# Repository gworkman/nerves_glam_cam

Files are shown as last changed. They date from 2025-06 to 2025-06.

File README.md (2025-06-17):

# Nerves Glam Cam

A Nerves-powered conference badge, first displayed at ElixirConf EU 2025.
Featuring an e-ink display and a tiny onboard camera, this project is designed
to showcase a fun use-case of Nerves.

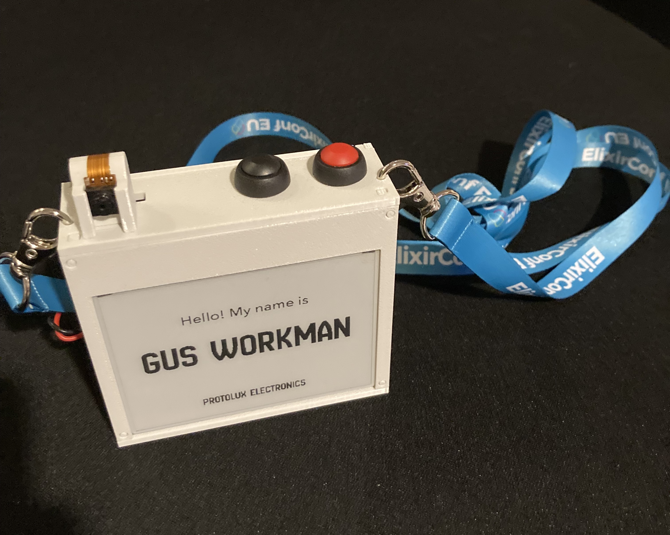
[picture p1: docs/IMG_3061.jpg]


> [!NOTE]
> Do you want to learn how to write an e-ink driver and get some e-ink hardware
> to take home? I'm running a workshop at several upcoming conferences, based on
> this project. Check it out -
> [ElixirConf US](https://elixirconf.com/trainings/dip-your-toes-into-hardware-with-nerves/)
> and
> [CodeBEAM Europe](https://codebeameurope.com/trainings/dip-your-toes-into-hardware-with-nerves/)
>
> Feel free to contact me if you're interested or have any questions!

## Functions

| Button | Press Type | Action |
| --- | --- | --- |
| Red | Any | Capture an image and show it on the display |
| Black  | Short | Cycle through the loaded slides |
| Black  | Long (5s)  | Power off (low power mode) |

## Hardware

Nerves Glam Cam is made of several components:

- Raspberry Pi Zero 2W
- [Soleil](https://protolux.io/projects/soleil) board for power management,
  battery charging and sleep mode
- 4.2", 400x300 e-ink display (I used
  [this one from Good Display](https://www.good-display.com/product/386.html))
- 24-pin e-ink SPI display adapter (I used
  [this one from Good Display](https://www.good-display.com/product/516.html))
- Tiny MIPI-CSI2 camera (I used
  [this OV5647-based one from AliExpress](https://www.aliexpress.com/item/32782501654.html))
- Some 3D printed parts and some superglue. STEP files are available in the
  [`mechanical`](/mechanical/README.md) directory

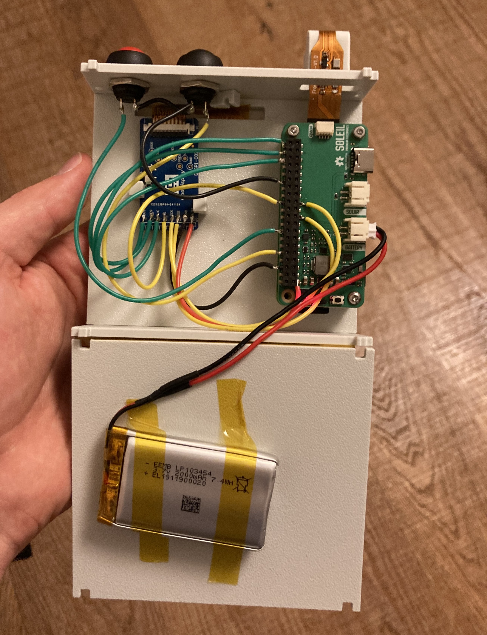
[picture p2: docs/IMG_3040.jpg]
Nerves Glam Cam - under the hood


## Key Implementation Details

It's a surprisingly small amount of code required to build this app and make it
run. There's two areas which are not super trivial though:

### E-Ink Display Driver

The e-ink display contains a SSD1683 driver chip, and is controlled using an SPI
interface. The `NervesGlamCam.EInk` module handles initialization, configuring
parameters like dimensions and operating mode, writing pixel data to the display
buffer, and enabling power-saving sleep mode.

The
[device datasheet](https://v4.cecdn.yun300.cn/100001_1909185148/GDEY042T81.pdf)
contains example code which served as the starting point for the software driver
in this repo.

### Image Processing

Images go through a standard processing pipeline to prepare them for display.
The source of the images can be static images (such as the pre-rendered slides,
which are just JPEG files) or dynamic images captured by the camera. First, an
image is converted to black and white, then resized to fit the screen
dimensions, and finally dithered using the Floyd-Steinberg algorithm. To handle
dithering, I cross compiled the Rust-based
[dither tool](https://crates.io/crates/dither) by Efron Licht. Finally, the
processed image is formatted to match the display driver requirements and
written to the buffer for rendering.

## Getting Started

If you've gone through the trouble of acquiring all the hardware, and want to
run this on your own device:

- `export MIX_TARGET=soleil_rpi0_2` or prefix every command with
  `MIX_TARGET=soleil_rpi0_2`. If you don't have the Soleil board for power
  management, you can also just use a target of `rpi0_2`.
- Set your WiFi credentials as environment variables, `NERVES_WIFI_SSID` and
  `NERVES_WIFI_PASSPHRASE`
- Install dependencies with `mix deps.get`
- Create firmware with `mix firmware`
- Burn to an SD card with `mix burn`

## Future Updates

The first version as shown at ElixirConf EU 2025 was bare-bones (I threw it
together in a weekend!). For the next conference, I'd like to make a few
updates:

- [ ] Support 4-bit grayscale for nicer images (especially text and fonts)
- [ ] Better button debounce
- [ ] More static slides
- [ ] Make it more social and interactive!

Stay tuned... v2 coming at Goatmire in September 2025 :eyes:

## Gallery

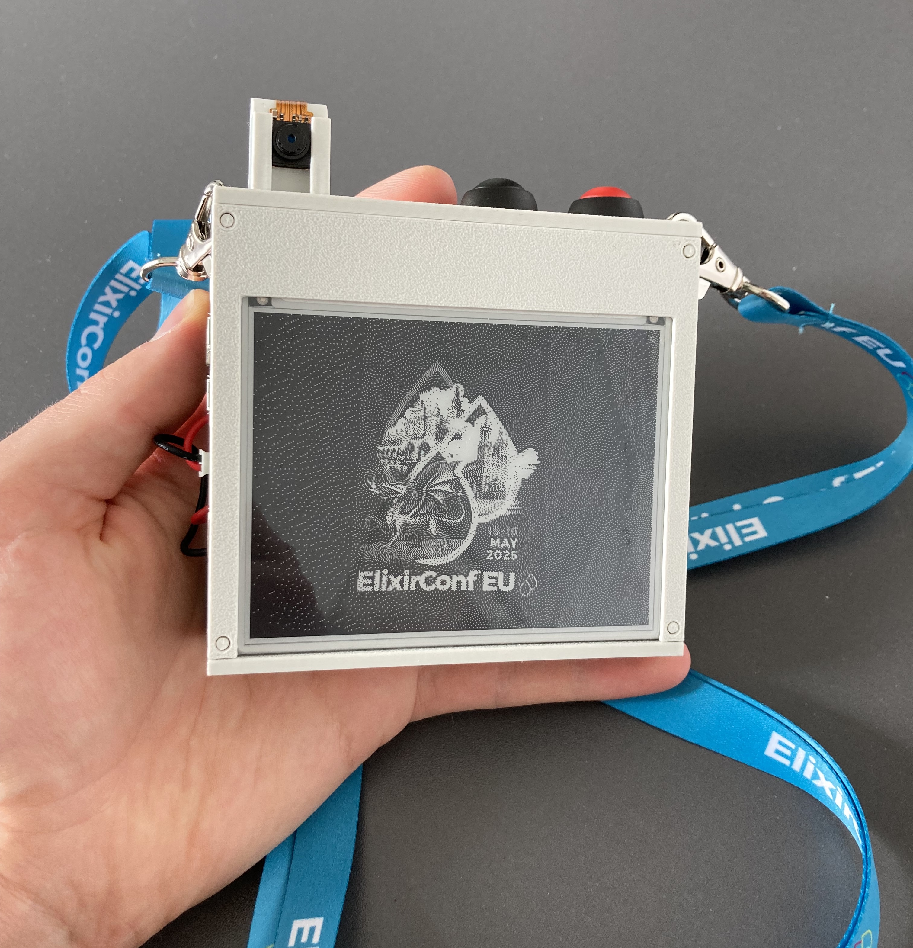
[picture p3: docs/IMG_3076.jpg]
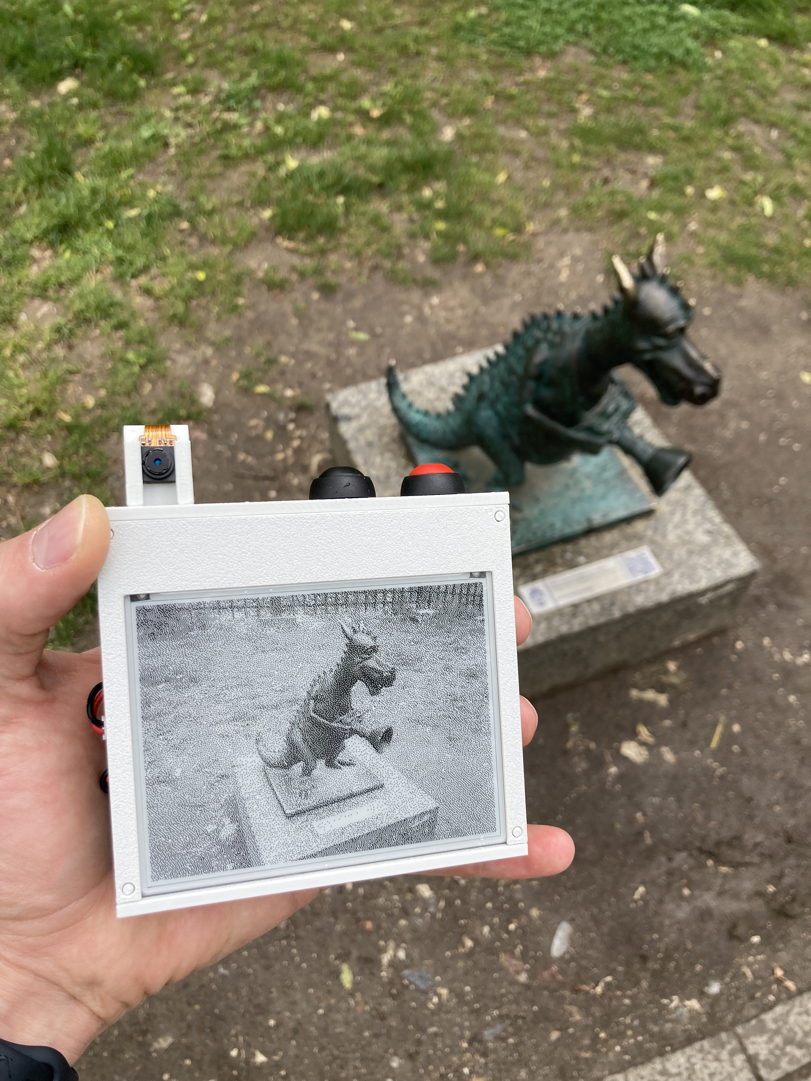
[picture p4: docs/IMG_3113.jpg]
 
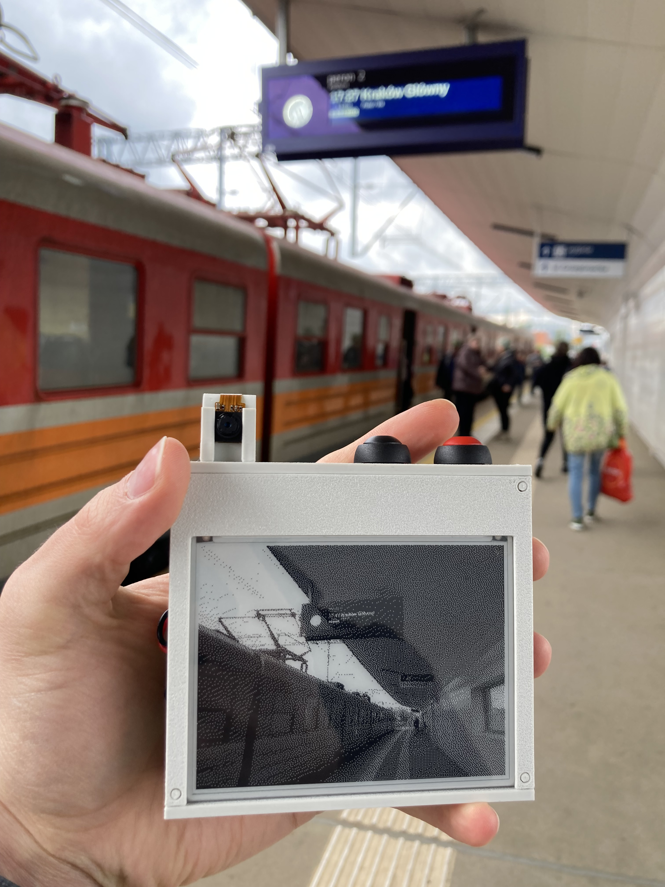
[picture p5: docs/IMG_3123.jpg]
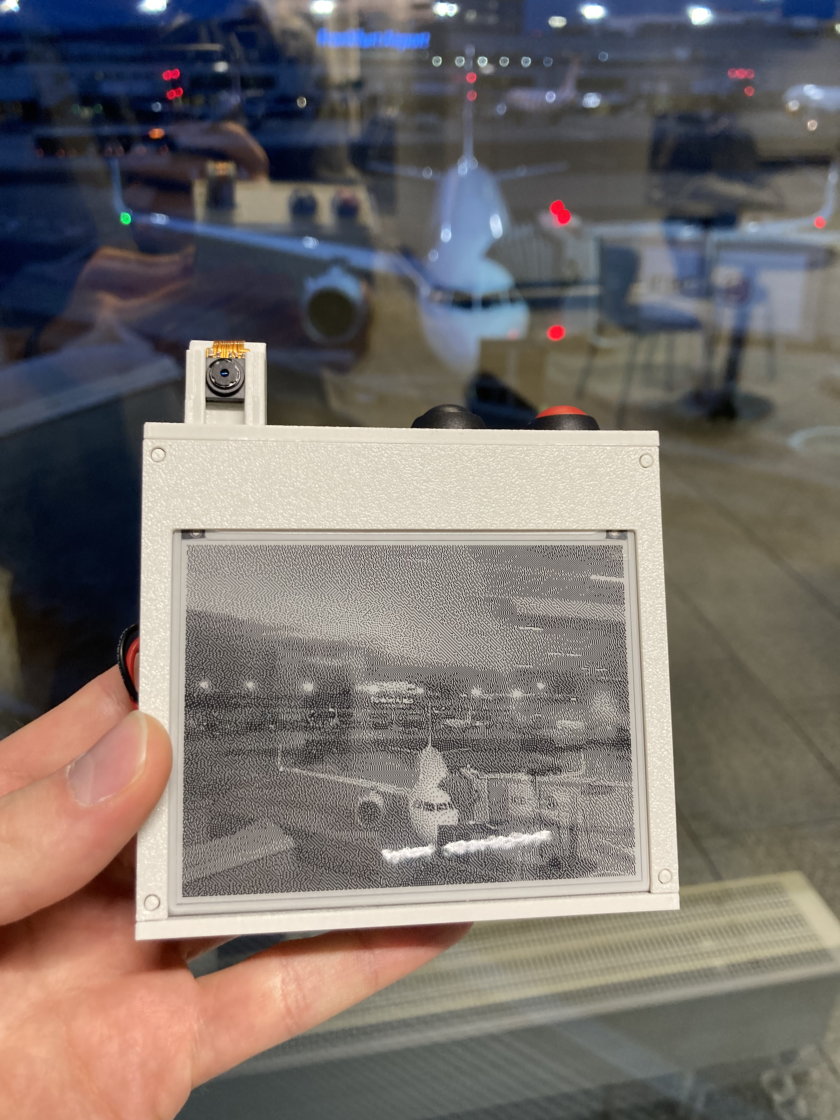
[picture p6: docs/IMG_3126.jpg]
 
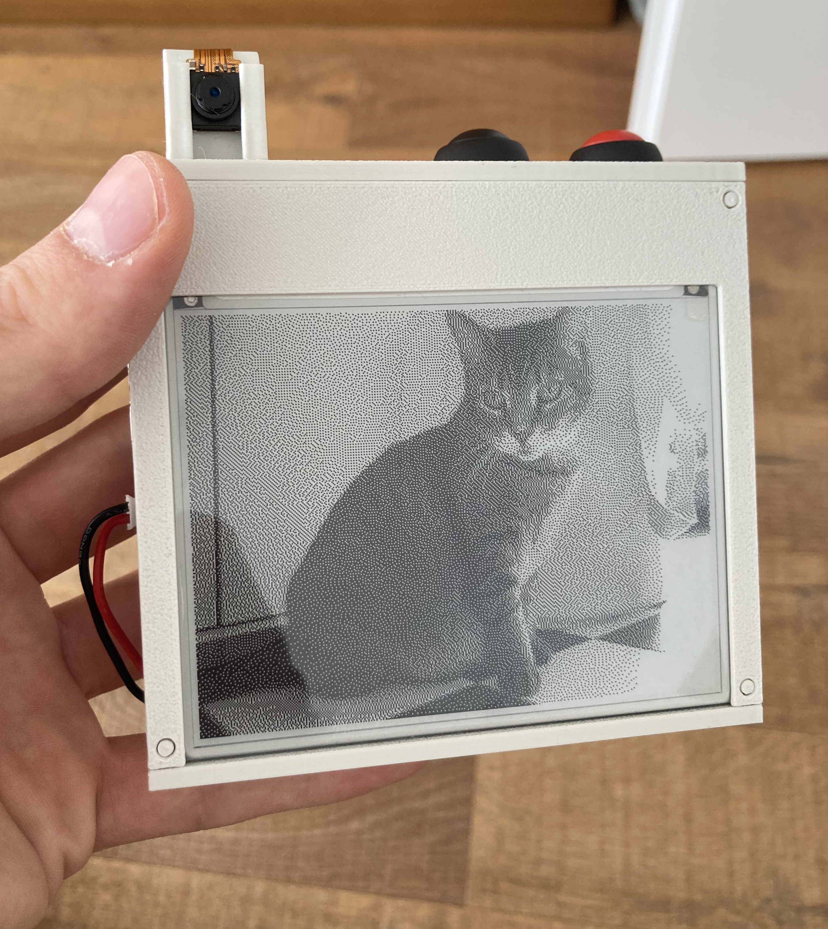
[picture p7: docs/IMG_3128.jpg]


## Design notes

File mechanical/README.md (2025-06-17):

# 3D Printed Case

This directory contains the STEP files for 3D printing a case for the hardware.

The parts are largely press-fit, but require superglue to stay together. For
parts such as the camera mount, spacers and board holder, placement does not
need to be precise. I glued them down after connecting all cables, to ensure
good cable management.

If you are making your own, here's what you need to print:

| File Name | Quantity |
| --- | --- |
| Back Plate.step | 1 |
| Bottom Plate.step | 1 |
| Camera Mount.step | 1 |
| EPD Clamp.step | 1 |
| Front Plate.step  | 1 |
| Top Plate.step | 1 |
| PCB Clamp.step | 2 |
| Spacer 1.step | 4 |
| Spacer 2.step | 4 |

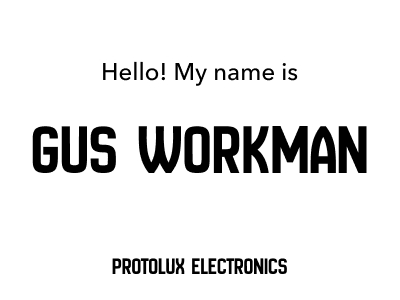
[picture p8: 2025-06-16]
priv/slides/nametag.jpg

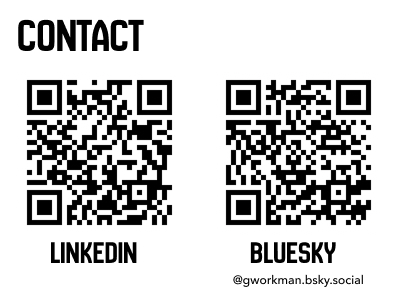
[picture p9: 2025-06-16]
priv/slides/z_contact.jpg

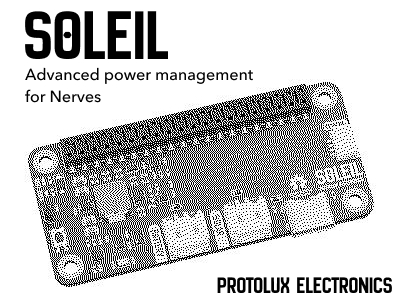
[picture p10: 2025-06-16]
priv/slides/soleil.jpg

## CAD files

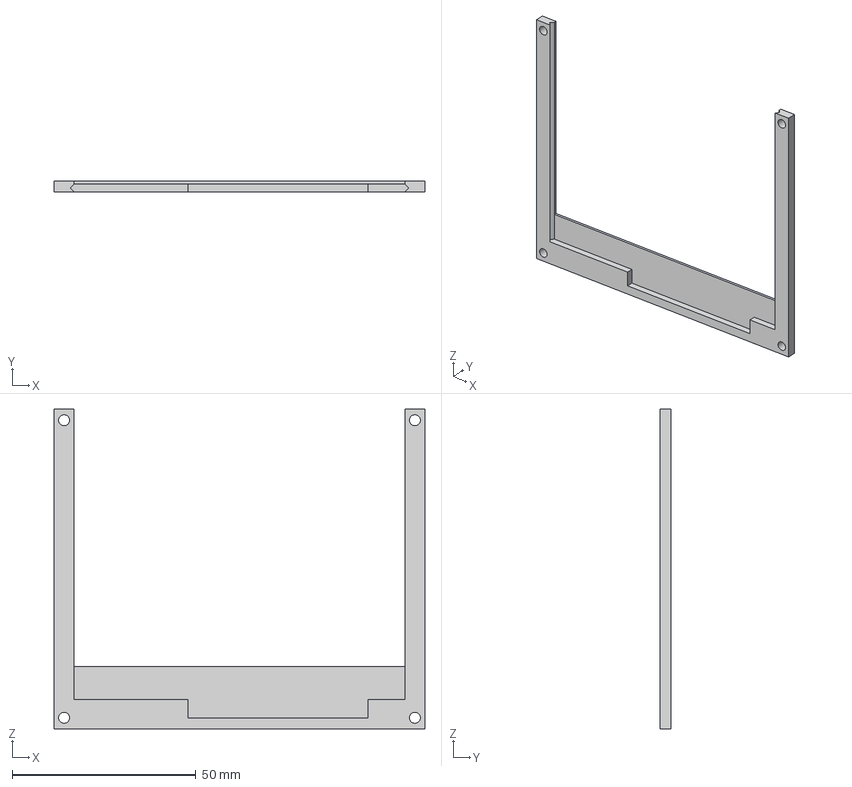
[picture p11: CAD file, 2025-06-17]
mechanical/EPD Clamp.step
101.0 x 3.00 x 87.0 mm

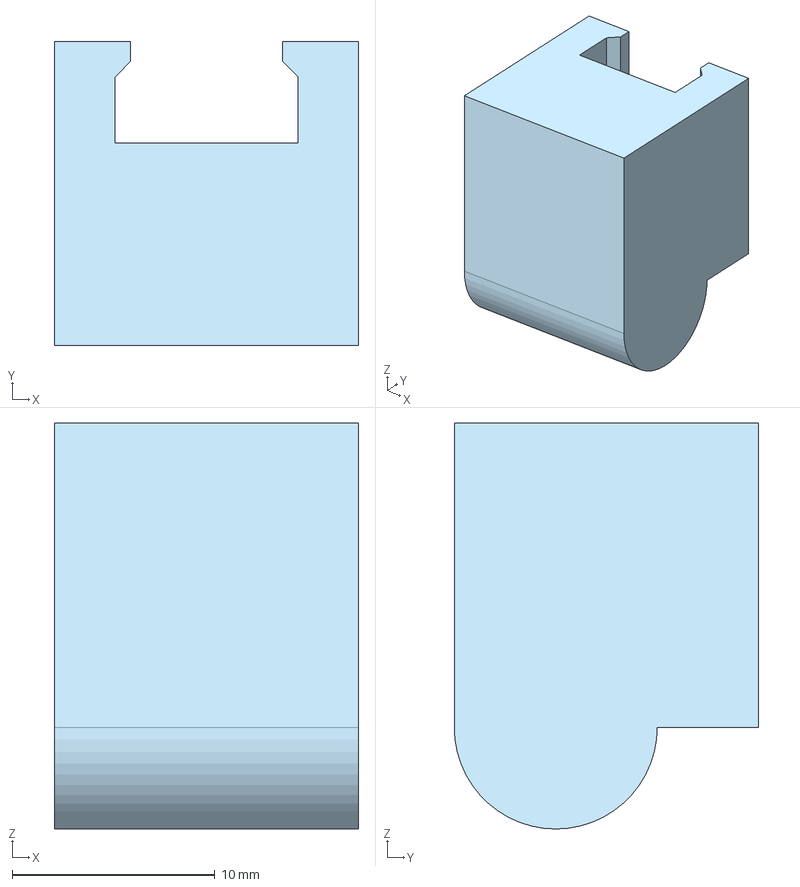
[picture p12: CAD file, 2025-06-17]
mechanical/Camera Mount.step
15.0 x 15.0 x 20.0 mm

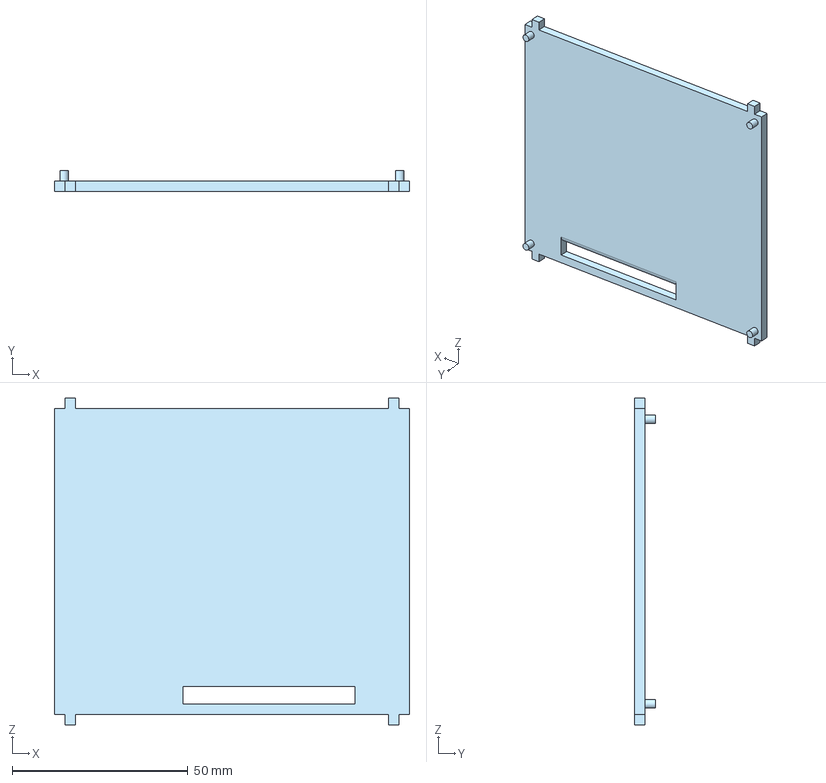
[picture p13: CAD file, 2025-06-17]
mechanical/Front Plate.step
101.0 x 6.00 x 93.0 mm

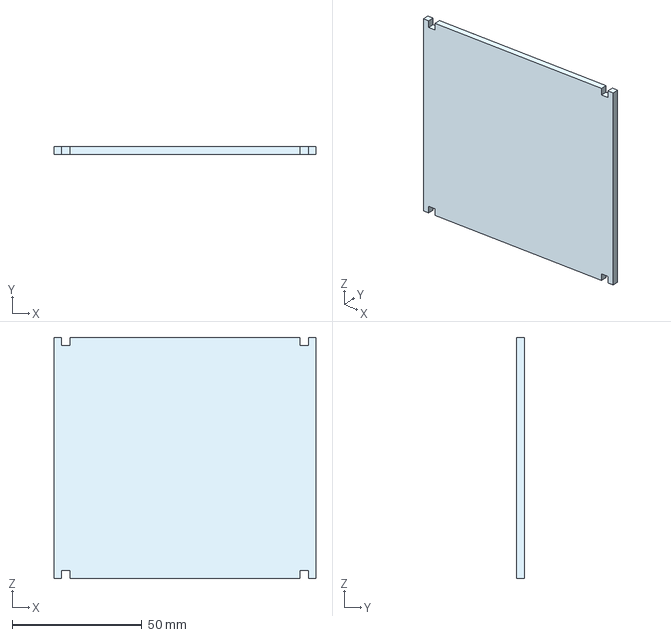
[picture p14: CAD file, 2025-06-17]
mechanical/Back Plate.step
101.0 x 3.00 x 93.0 mm

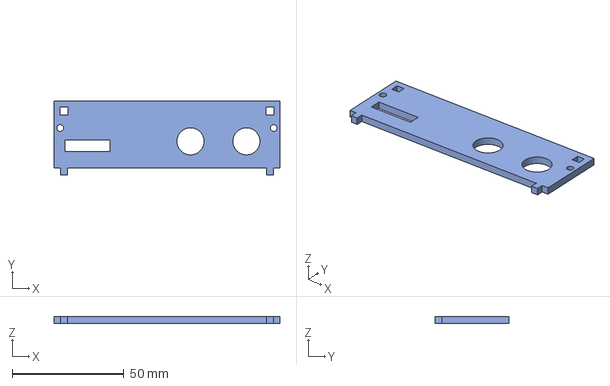
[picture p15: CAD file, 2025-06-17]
mechanical/Top Plate.step
101.0 x 33.0 x 3.00 mm

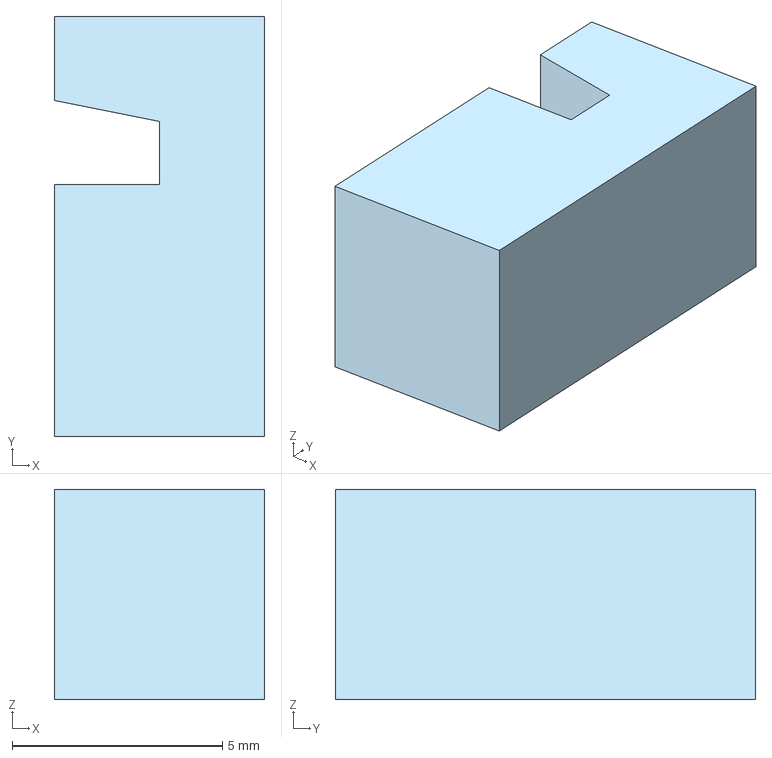
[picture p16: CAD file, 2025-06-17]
mechanical/PCB Clamp.step
5.00 x 10.0 x 5.00 mm

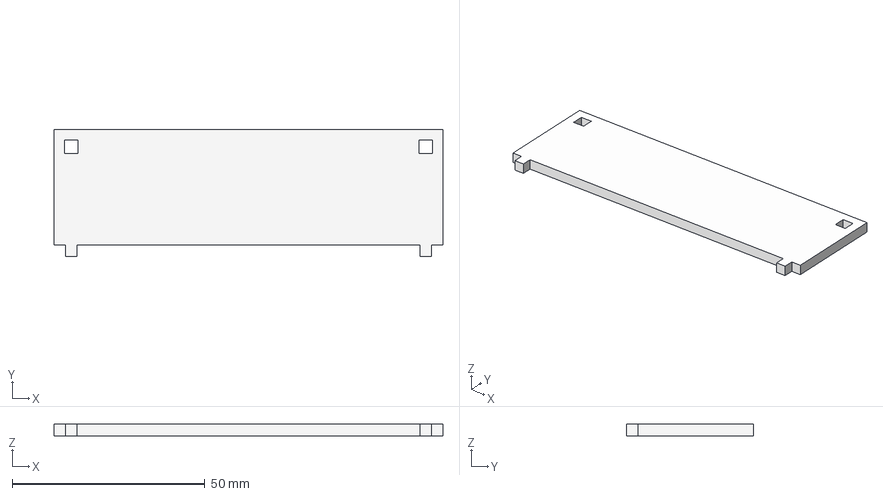
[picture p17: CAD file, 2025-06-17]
mechanical/Bottom Plate.step
101.0 x 33.0 x 3.00 mm

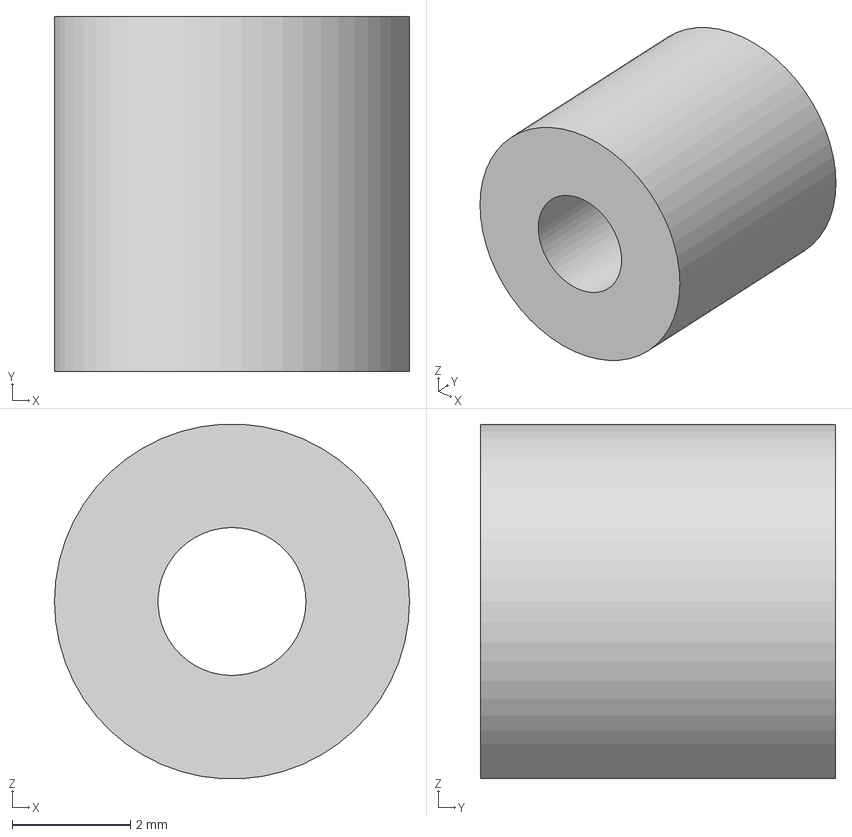
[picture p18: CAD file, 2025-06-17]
mechanical/Spacer 1.step
6.00 x 6.00 x 5.99 mm

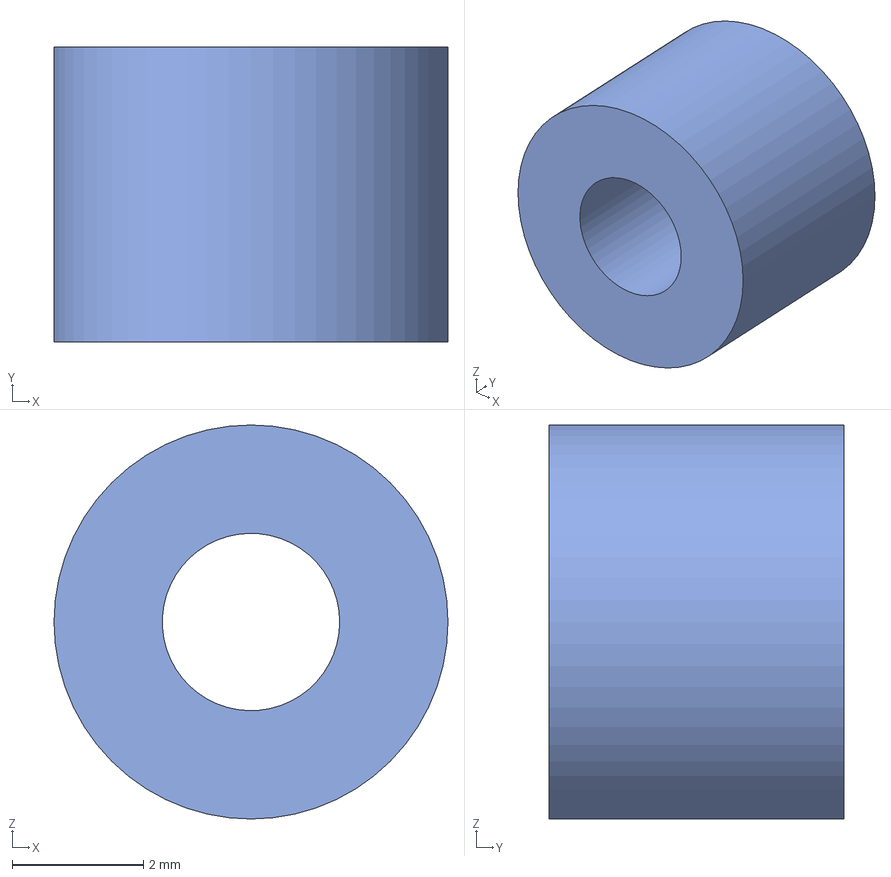
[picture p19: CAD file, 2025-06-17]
mechanical/Spacer 2.step
6.00 x 4.50 x 6.00 mm
